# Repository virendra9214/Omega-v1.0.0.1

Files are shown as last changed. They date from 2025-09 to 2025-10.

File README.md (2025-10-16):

Omega – ESP32 STEM Controller Board

Omega is an ESP32-based controller board created by  VIRENDRA SINGH SHEKHAWAT from India to make STEM education, robotics, and IoT more accessible.  
It combines Wi-Fi, BLE, sensor inputs, motor drivers, and easy expansion in one compact design — perfect for classrooms, tinkering labs, hobbyists, and competitions.


  


---

Key Features
- MCU: ESP32-WROOM-32E (Dual-core, Wi-Fi + BLE)
- Programming: Arduino IDE, MicroPython, block-based IDE (PictoBlox-style)
- Motors & Servos:
  - 2× TB6612FNG motor drivers (up to 4 12v motors)
  - 3× Servo headers (5 V PWM)
- Sensors Supported:
  - Ultrasonic, IR, MPU6050 IMU, Color sensor, DHT, analog/digital expansion
- Outputs:
  - WS2812B RGB LED
  - PAM8403 speaker amplifier
- Connectivity:
  - I²C, UART, PWM, ADC, DAC via JST connectors
- Power:
  - Auto USB-C / 12 V barrel jack switching (FDN340P MOSFET)
  - Onboard 5 V & 3.3 V regulation with fuse, diodes, ESD protection

---

 Educational Value
- Free for students, hobbyists, and individual educators.
- Supports hands-on STEM learning: electronics, coding, IoT, robotics
- Beginner-friendly with block-based coding
- Expandable for advanced learners with C++/Python
- Supports Indian education initiatives (NEP 2020, Skill India, Atal Tinkering Labs)

---

Example Projects
- IoT-based smart irrigation system  
- Accident detection and car safety module  
- Line follower / obstacle avoiding robots  
- BLE remote-controlled car  
- Classroom experiments: data logging, servo control, LED patterns  

---

 Repository Contents
- `/Production` → KiCad schematic, PCB, BOM  
- `/firmware` → Arduino / MicroPython example codes  
- `/datasheets` → Datasheets, pin mapping, tutorials  
- `/codes` → Ready-to-run projects for students and testing after production 

---

License
This project is released under the Omega Educational License (OEL-1.0).  
-  Free for education, research, and personal use  
-  Commercial use requires a paid license from the creator  
-  Significant design modifications and redistributions are not allowed  
youtube link:https://www.youtube.com/@LEARN_OMEGA
📩 Contact: virendrasinghshekhawat786@gmail.com for commercial licensing inquiries.







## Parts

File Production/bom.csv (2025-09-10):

Designator | Footprint | Quantity | Value | LCSC Part #
_3, _2, |  | 3
C1, C11, C2, C39, C40, C41, C42, C43, C44, C5 | 0805 | 10 | 100nf
C10, C12 | 0805 | 2 | 10uf
C25, C26 | 0603 | 2 | 10nf
C27 | 0603 | 1 | 2.2nf/16v
C28, C49, C50, C51 | 0603 | 4 | 0.1uf
C29, C30 | CAP_EEETC1V470V | 2 | 47uf/35v
C31, C32 | 0805 | 2 | 100n
C33, C34 | 0805 | 2 | 47uf/25v
C35, C36, C57 | 0805 | 3 | 0.1uf
C37 | 0603 | 1 | 10uf/25v
C38 | 0603 | 1 | 1uf/16V(10%)
C47, C48 | CAP_EEETC1V470V | 2 | 470uf/25V
C52 | 0603 | 1 | 10uF
C53, C54 | 0805 | 2 | 1uf
C55 | 0805 | 1 | 0.47uf
D1 | LED_WS2812B_PLCC4_5.0x5.0mm_P3.2mm | 1 | WS2812B
D3 | D_SMA | 1 | M7
D4 | 0805 | 1 | LED(RED)
D5 | 0805 | 1 | LED
D6 | D_SOD-123 | 1 | 1N5819
D7 | 0805 | 1 | LED (BLUE)
D8 | 0805 | 1 | LED (GREEN)
F1 | FUSER_MF-MSMF110_16-2 | 1 | MF-MSMF110_16-2
J10 | JST_EH_B4B-EH-A_1x04_P2.50mm_Vertical | 1 | ULTRASONIC
J17 | JST_EH_B5B-EH-A_1x05_P2.50mm_Vertical | 1 | POWER
J18 | JST_EH_B3B-EH-A_1x03_P2.50mm_Vertical | 1 | IR1
J20 | BarrelJack_GCT_DCJ200-10-A_Horizontal | 1 | DCJ200-10-A-XX-K_REVA
J21 | JST_EH_B2B-EH-A_1x02_P2.50mm_Vertical | 1 | M1
J22 | JST_EH_B2B-EH-A_1x02_P2.50mm_Vertical | 1 | M2
J23 | JST_EH_B2B-EH-A_1x02_P2.50mm_Vertical | 1 | M3
J25 | JST_EH_B3B-EH-A_1x03_P2.50mm_Vertical | 1 | IR2
J26 | JST_EH_B7B-EH-A_1x07_P2.50mm_Vertical | 1 | Conn_01x07_Socket
J27 | JST_EH_B3B-EH-A_1x03_P2.50mm_Vertical | 1 | S1
J28 | JST_EH_B3B-EH-A_1x03_P2.50mm_Vertical | 1 | S2
J29 | JST_EH_B2B-EH-A_1x02_P2.50mm_Vertical | 1 | Speaker
JUSB1 | USB_C_Receptacle_GCT_USB4105-xx-A_16P_TopMnt_Horizontal | 1 | USB_C_Receptacle_USB2.0
Q1 | SuperSOT-3 | 1 | FDN340P
Q4, Q5 | SOT-23 | 2 | SS8050
R1, R17, R2 | 0805 | 3 | 5.1k
R13 | 0603 | 1 | 1k
R14, R15, R16, R4, R5 | 0603 | 5 | 4.7k
R18, R19 | 0805 | 2 | 10k
R20, R36, R37 | 0805 | 3 | 1k
R21 | 0603 | 1 | 22.1k(1%)
R22 | 0603 | 1 | 47.5k(1%)
R23 | 0603 | 1 | 1k(1%)
R24 | 0603 | 1 | 10k(1%)(NC)
R25, R26, R29, R30 | 0603 | 4 | 0(1%)
R27, R28 | 0603 | 2 | 10k(1%)
R31, R32 | 0603 | 2 | 10k
R35 | 0805 | 1 | 10k(1%)
R9 | 0603 | 1 | 100k
SW1 | SW_SPST_PTS810 | 1 | BOOT
SW2 | SW_SPST_PTS810 | 1 | RESET
U10 | SOT230P700X180-4N | 1 | NCP1117ST50T3G
U11 | MSOP-8_3x3mm_P0.65mm | 1 | LMV358IDGK
U12 | SOT-223-3_TabPin2 | 1 | AMS1117-3.3
U13 | QFN-28-1EP_5x5mm_P0.5mm_EP3.35x3.35mm | 1 | CP2102N-A02-GQFN28
U14, U15 | SSOP-24_5.3x8.2mm_P0.65mm | 2 | TB6612FNG
U16 | SOP-16_3.9x9.9mm_P1.27mm | 1 | PAM8403D
U18 | ESP32-WROOM-32 | 1 | ESP32-WROOM-32
U2 | Diodes_UDFN-10_1.0x2.5mm_P0.5mm | 1 | ESD7104MUTAG
U6 | InvenSense_QFN-24_4x4mm_P0.5mm | 1 | MPU-6050
U8 | TSSOP-20_4.4x6.5mm_P0.65mm | 1 | TXS0108EPW

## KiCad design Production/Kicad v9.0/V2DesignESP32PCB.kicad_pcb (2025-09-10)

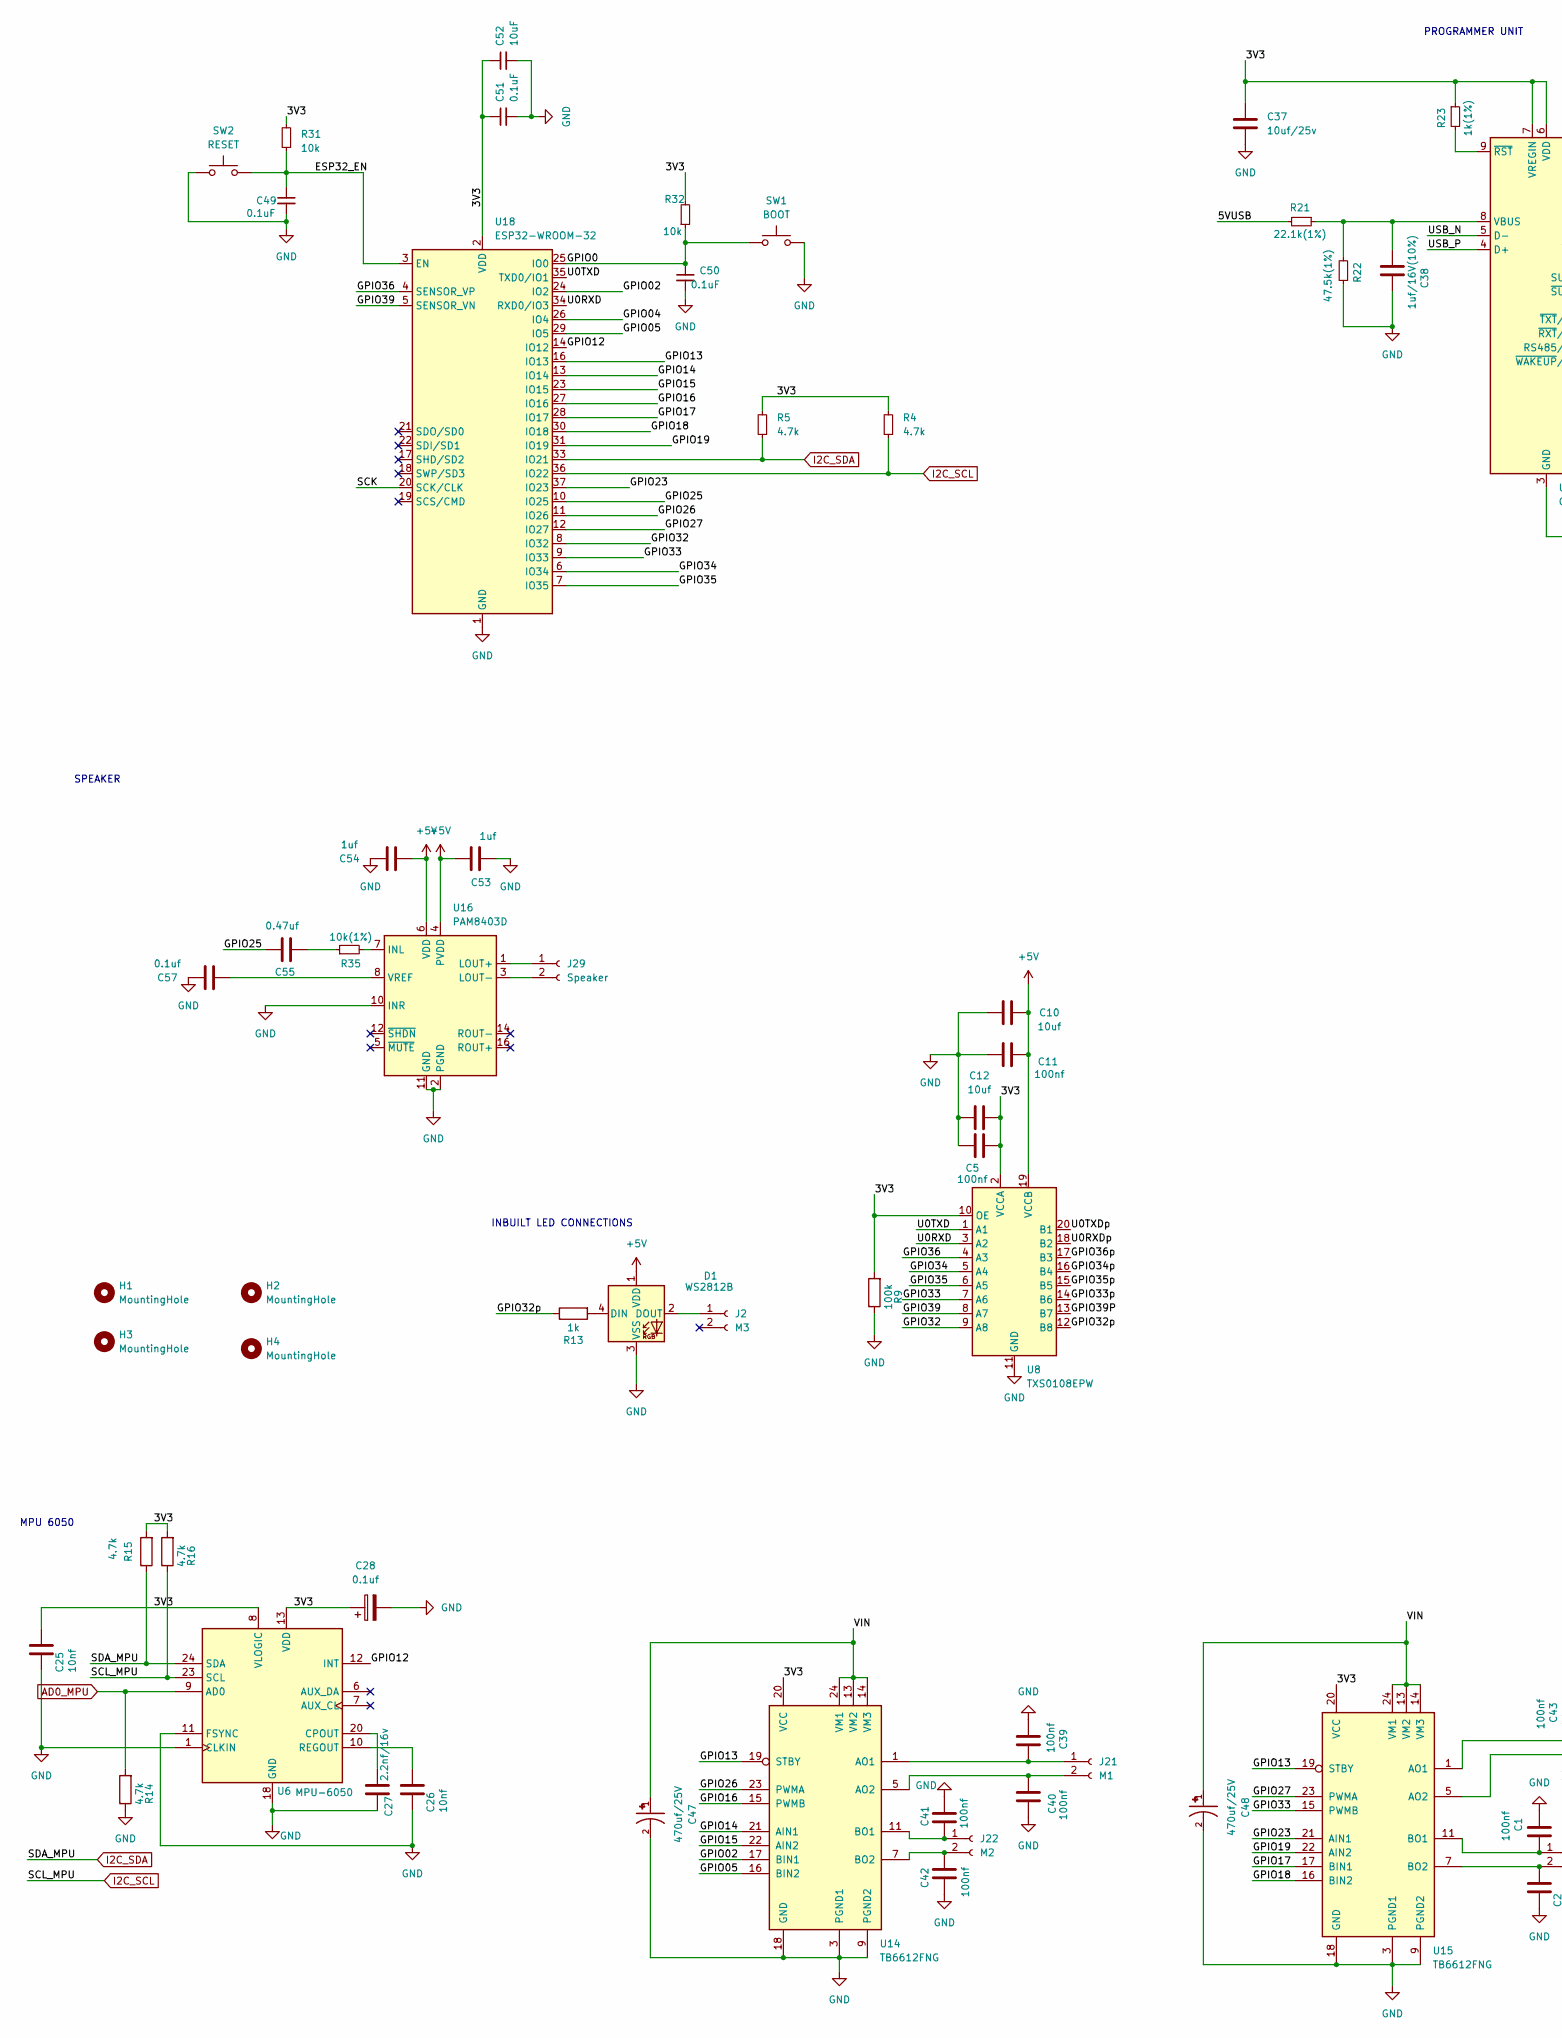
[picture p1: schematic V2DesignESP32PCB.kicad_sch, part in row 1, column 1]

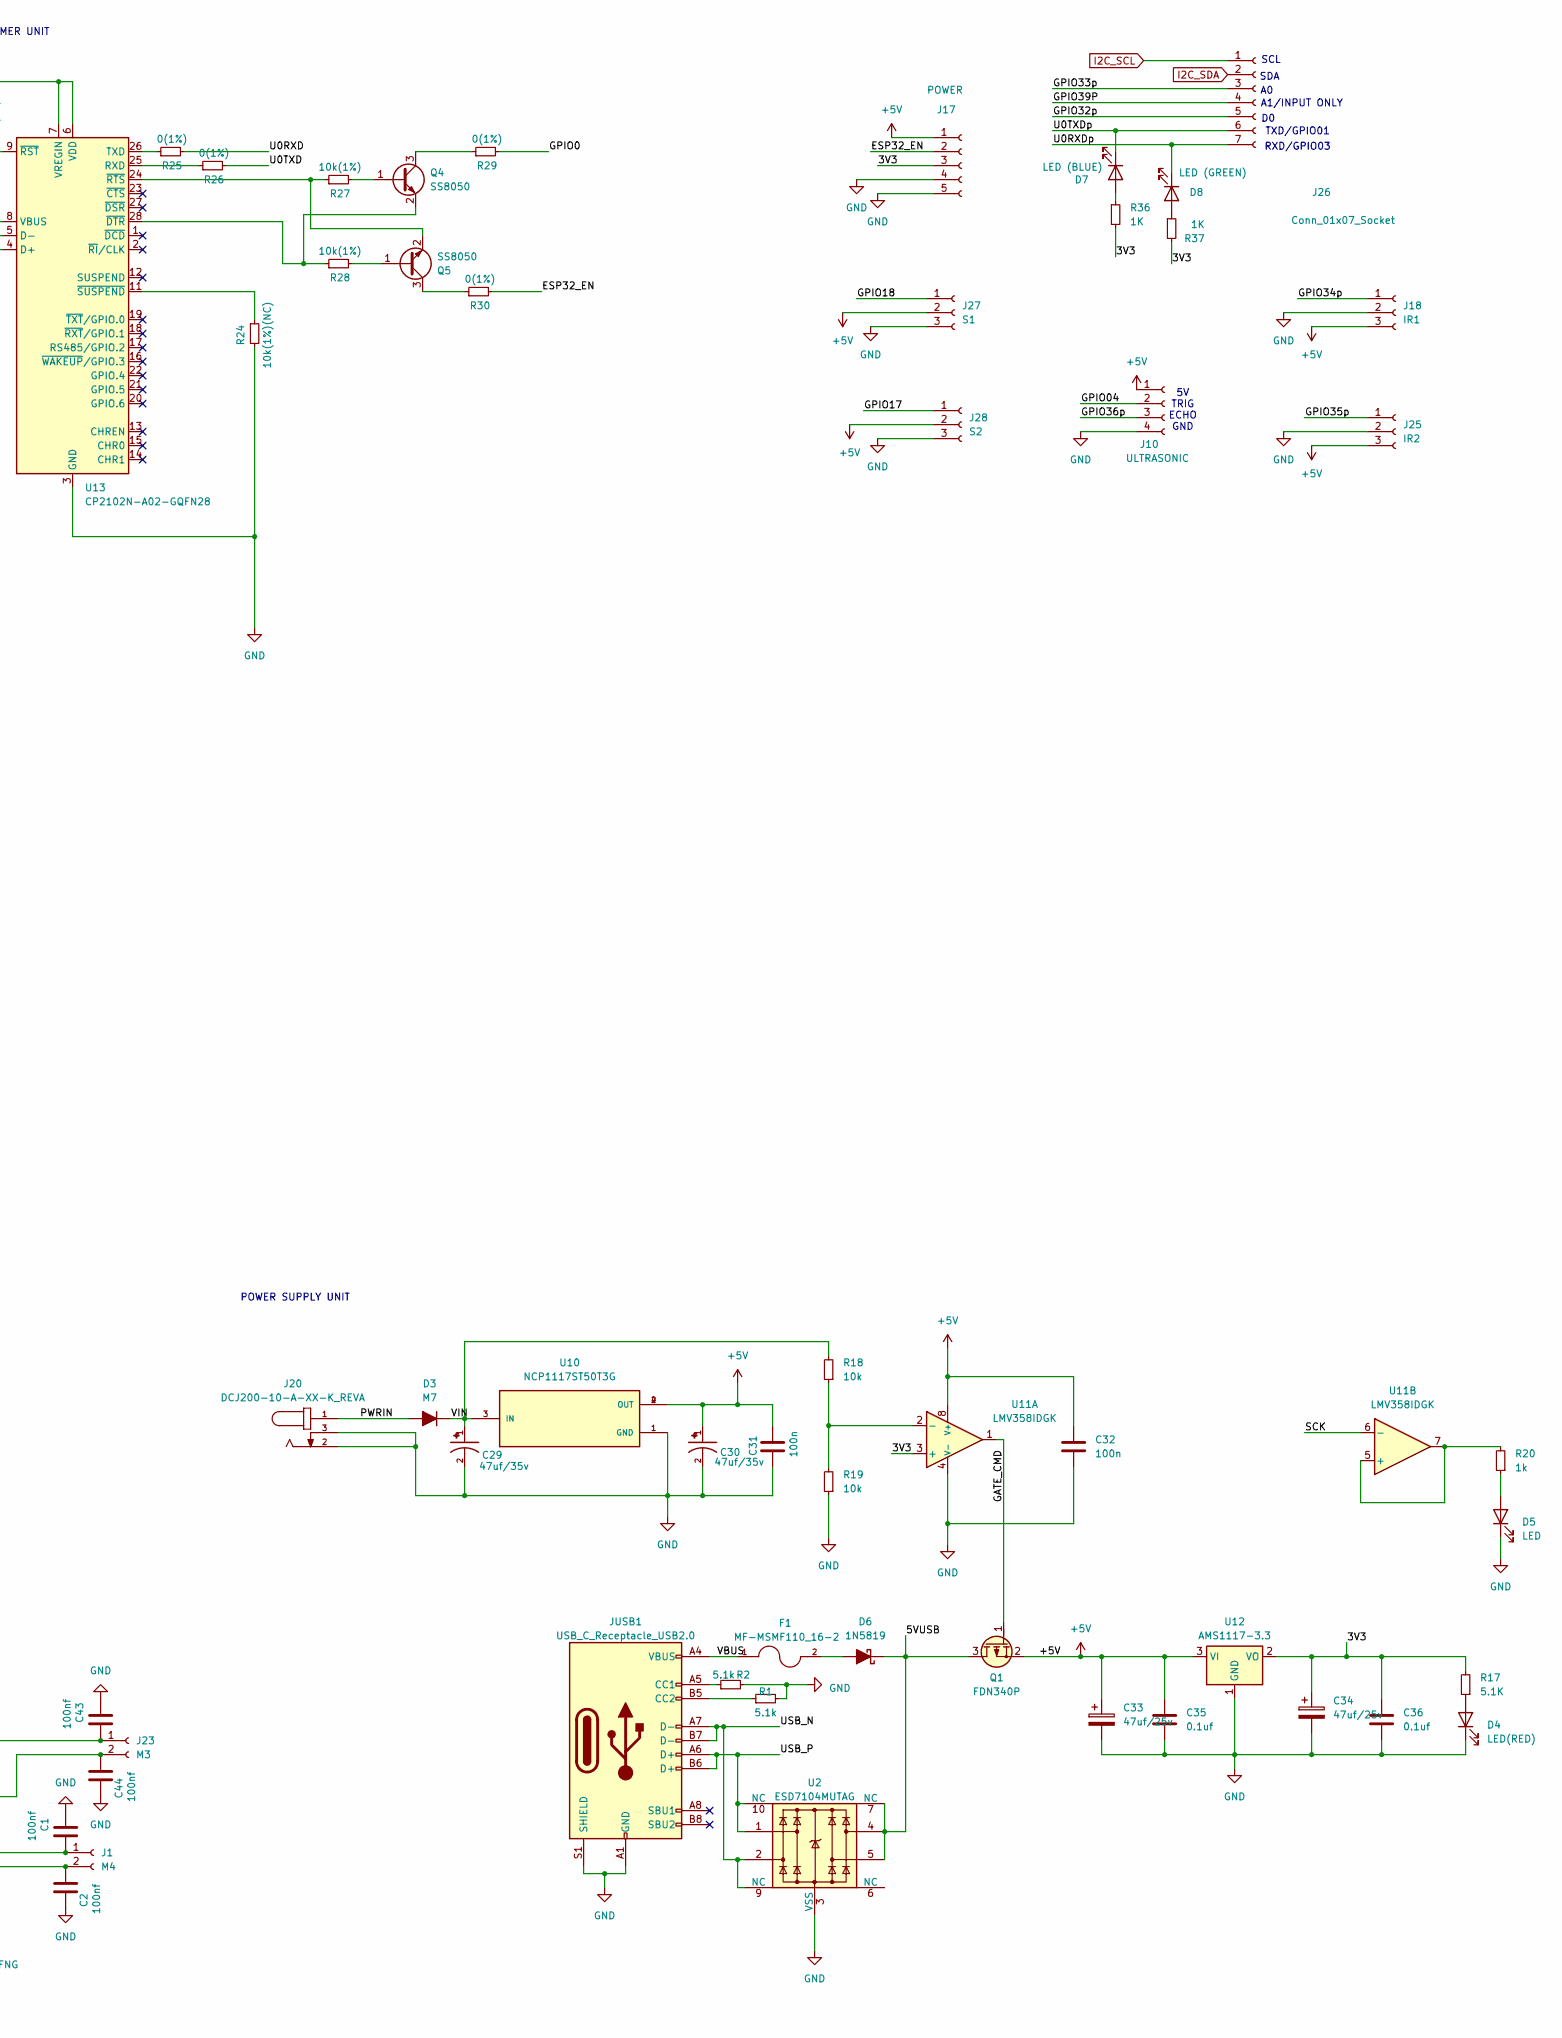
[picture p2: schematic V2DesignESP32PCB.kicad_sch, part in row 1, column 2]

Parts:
C1, C2, C5, C11, C39, C40, C41, C42, C43, C44: 100nf; C_0805_2012Metric
C10, C12: 10uf; C_0805_2012Metric
C25, C26: 10nf; C_0603_1608Metric
C27: 2.2nf/16v; C_0603_1608Metric
C28: 0.1uf; C_0603_1608Metric
C29, C30: 47uf/35v; CAP_EEETC1V470V; PARTREV 10-Oct-19
C31, C32: 100n; C_0805_2012Metric
C33, C34: 47uf/25v; C_0805_2012Metric
C35, C36, C57: 0.1uf; C_0805_2012Metric
C37: 10uf/25v; C_0603_1608Metric
C38: 1uf/16V(10%); C_0603_1608Metric
C47, C48: 470uf/25V; CAP_EEETC1V470V; PARTREV 10-Oct-19
C49, C50, C51: 0.1uF; C_0603_1608Metric; MANUFECTURER PART NUMBER ${ITEM_NUMBER}
C52: 10uF; C_0603_1608Metric; MANUFECTURER PART NUMBER ${ITEM_NUMBER}
C53, C54: 1uf; C_0805_2012Metric
C55: 0.47uf; C_0805_2012Metric
D1: WS2812B; LED_WS2812B_PLCC4_5.0x5.0mm_P3.2mm; MANUFECTURER PART NUMBER ${ITEM_NUMBER}
D3: M7; D_SMA
D4: LED(RED); LED_0805_2012Metric; MANUFECTURER PART NUMBER ${ITEM_NUMBER}
D5: LED; LED_0805_2012Metric; MANUFECTURER PART NUMBER ${ITEM_NUMBER}
D6: 1N5819; D_SOD-123
D7: LED (BLUE); LED_0805_2012Metric; MANUFECTURER PART NUMBER ${ITEM_NUMBER}
D8: LED (GREEN); LED_0805_2012Metric; MANUFECTURER PART NUMBER ${ITEM_NUMBER}
F1: MF-MSMF110_16-2; FUSER_MF-MSMF110_16-2
H1, H2, H3, H4: MountingHole; MountingHole_4mm
J1: M4; MANUFECTURER PART NUMBER ${ITEM_NUMBER}
J2, J23: M3; JST_EH_B2B-EH-A_1x02_P2.50mm_Vertical; MANUFECTURER PART NUMBER ${ITEM_NUMBER}
J10: ULTRASONIC; JST_EH_B4B-EH-A_1x04_P2.50mm_Vertical; MANUFECTURER PART NUMBER ${ITEM_NUMBER}
J17: POWER; JST_EH_B5B-EH-A_1x05_P2.50mm_Vertical
J18: IR1; JST_EH_B3B-EH-A_1x03_P2.50mm_Vertical; MANUFECTURER PART NUMBER ${ITEM_NUMBER}
J20: DCJ200-10-A-XX-K_REVA; BarrelJack_GCT_DCJ200-10-A_Horizontal; PARTREV A
J21: M1; JST_EH_B2B-EH-A_1x02_P2.50mm_Vertical; MANUFECTURER PART NUMBER ${ITEM_NUMBER}
J22: M2; JST_EH_B2B-EH-A_1x02_P2.50mm_Vertical; MANUFECTURER PART NUMBER ${ITEM_NUMBER}
J25: IR2; JST_EH_B3B-EH-A_1x03_P2.50mm_Vertical; MANUFECTURER PART NUMBER ${ITEM_NUMBER}
J26: Conn_01x07_Socket; JST_EH_B7B-EH-A_1x07_P2.50mm_Vertical
J27: S1; JST_EH_B3B-EH-A_1x03_P2.50mm_Vertical; MANUFECTURER PART NUMBER ${ITEM_NUMBER}
J28: S2; JST_EH_B3B-EH-A_1x03_P2.50mm_Vertical; MANUFECTURER PART NUMBER ${ITEM_NUMBER}
J29: Speaker; JST_EH_B2B-EH-A_1x02_P2.50mm_Vertical; MANUFECTURER PART NUMBER ${ITEM_NUMBER}
JUSB1: USB_C_Receptacle_USB2.0; USB_C_Receptacle_GCT_USB4105-xx-A_16P_TopMnt_Horizontal; MANUFECTURER PART NUMBER ${ITEM_NUMBER}
Q1: FDN340P; SuperSOT-3
Q4, Q5: SS8050; SOT-23
R1, R2: 5.1k; R_0805_2012Metric; MANUFECTURER PART NUMBER ${ITEM_NUMBER}
R4, R5: 4.7k; R_0603_1608Metric; MANUFECTURER PART NUMBER ${ITEM_NUMBER}
R9: 100k; R_0603_1608Metric
R13: 1k; R_0603_1608Metric
R14, R15, R16: 4.7k; R_0603_1608Metric
R17: 5.1K; R_0805_2012Metric; MANUFECTURER PART NUMBER ${ITEM_NUMBER}
R18, R19: 10k; R_0805_2012Metric; MANUFECTURER PART NUMBER ${ITEM_NUMBER}
R20: 1k; R_0805_2012Metric; MANUFECTURER PART NUMBER ${ITEM_NUMBER}
R21: 22.1k(1%); R_0603_1608Metric; MANUFECTURER PART NUMBER ${ITEM_NUMBER}
R22: 47.5k(1%); R_0603_1608Metric; MANUFECTURER PART NUMBER ${ITEM_NUMBER}
R23: 1k(1%); R_0603_1608Metric; MANUFECTURER PART NUMBER ${ITEM_NUMBER}
R24: 10k(1%)(NC); R_0603_1608Metric; MANUFECTURER PART NUMBER ${ITEM_NUMBER}
R25, R26, R29, R30: 0(1%); R_0603_1608Metric; MANUFECTURER PART NUMBER ${ITEM_NUMBER}
R27, R28: 10k(1%); R_0603_1608Metric; MANUFECTURER PART NUMBER ${ITEM_NUMBER}
R31, R32: 10k; R_0603_1608Metric; MANUFECTURER PART NUMBER ${ITEM_NUMBER}
R35: 10k(1%); R_0805_2012Metric; MANUFECTURER PART NUMBER ${ITEM_NUMBER}
R36, R37: 1K; R_0805_2012Metric; MANUFECTURER PART NUMBER ${ITEM_NUMBER}
SW1: BOOT; SW_SPST_PTS810
SW2: RESET; SW_SPST_PTS810
U2: ESD7104MUTAG; Diodes_UDFN-10_1.0x2.5mm_P0.5mm; MANUFECTURER PART NUMBER ${ITEM_NUMBER}
U6: MPU-6050; InvenSense_QFN-24_4x4mm_P0.5mm
U8: TXS0108EPW; TSSOP-20_4.4x6.5mm_P0.65mm
U10: NCP1117ST50T3G; SOT230P700X180-4N; DigiKey_Part_Number NCP1117ST50T3GOSTR-ND
U11: LMV358IDGK; MSOP-8_3x3mm_P0.65mm
U12: AMS1117-3.3; SOT-223-3_TabPin2
U13: CP2102N-A02-GQFN28; QFN-28-1EP_5x5mm_P0.5mm_EP3.35x3.35mm
U14, U15: TB6612FNG; SSOP-24_5.3x8.2mm_P0.65mm
U16: PAM8403D; SOP-16_3.9x9.9mm_P1.27mm
U18: ESP32-WROOM-32

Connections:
+5V: C10.2, C11.1, C30.1, C31.1, C32.1, C33.1, C35.1, C53.2, C54.1, D1.1 (VDD), J10.1, J17.1, J18.3, J25.3, J27.2, J28.2, Q1.2 (S), U8.19 (VCCB), U10.2 (OUT), U10.4 (OUT), U11.8 (V+), U12.3 (VI), U16.4 (PVDD), U16.6 (VDD), U16.13 (PVDD)
/3V3: C5.1, C12.2, C25.1, C28.1, C34.1, C36.1, C37.1, C51.1, C52.1, J17.3, R4.2, R5.2, R9.2, R15.2, R16.2, R17.2, R23.1, R31.2, R32.2, R36.2, R37.2, U6.8 (VLOGIC), U6.13 (VDD), U8.2 (VCCA), U8.10 (OE), U11.3 (+), U12.2 (VO), U13.6 (VDD), U13.7 (VREGIN), U14.20 (VCC), U15.20 (VCC), U18.2 (VDD)
/5VUSB: D6.1 (K), Q1.3 (D), R21.2, U2.4, U2.5, U2.7 (NC)
/ESP32_EN: C49.1, J17.2, R30.2, R31.1, SW2.2, U18.3 (EN)
/GATE_CMD: Q1.1 (G), U11.1
/GPIO0: C50.1, R29.2, R32.1, SW1.1, U18.25 (IO0)
/GPIO02: U14.17 (BIN1), U18.24 (IO2)
/GPIO04: J10.2, U18.26 (IO4)
/GPIO05: U14.16 (BIN2), U18.29 (IO5)
/GPIO12: U6.12 (INT), U18.14 (IO12)
/GPIO13: U14.19 (STBY), U15.19 (STBY), U18.16 (IO13)
/GPIO14: U14.21 (AIN1), U18.13 (IO14)
/GPIO15: U14.22 (AIN2), U18.23 (IO15)
/GPIO16: U14.15 (PWMB), U18.27 (IO16)
/GPIO17: J28.1, U15.17 (BIN1), U18.28 (IO17)
/GPIO18: J27.1, U15.16 (BIN2), U18.30 (IO18)
/GPIO19: U15.22 (AIN2), U18.31 (IO19)
/GPIO23: U15.21 (AIN1), U18.37 (IO23)
/GPIO25: C55.2, U18.10 (IO25)
/GPIO26: U14.23 (PWMA), U18.11 (IO26)
/GPIO27: U15.23 (PWMA), U18.12 (IO27)
/GPIO32: U8.9 (A8), U18.8 (IO32)
/GPIO32p: J26.5, R13.1, U8.12 (B8)
/GPIO33: U8.7 (A6), U15.15 (PWMB), U18.9 (IO33)
/GPIO33p: J26.3, U8.14 (B6)
/GPIO34: U8.5 (A4), U18.6 (IO34)
/GPIO34p: J18.1, U8.16 (B4)
/GPIO35: U8.6 (A5), U18.7 (IO35)
/GPIO35p: J25.1, U8.15 (B5)
/GPIO36: U8.4 (A3), U18.4 (SENSOR_VP)
/GPIO36p: J10.3, U8.17 (B3)
/GPIO39: U8.8 (A7), U18.5 (SENSOR_VN)
/GPIO39P: J26.4, U8.13 (B7)
/PWRIN: D3.2 (A), J20.1
/SCK: U11.6 (-), U18.20 (SCK/CLK)
/U0RXD: R25.2, U8.3 (A2), U18.34 (RXD0/IO3)
/U0RXDp: D8.1 (K), J26.7, U8.18 (B2)
/U0TXD: R26.2, U8.1 (A1), U18.35 (TXD0/IO1)
/U0TXDp: D7.1 (K), J26.6, U8.20 (B1)
/USB_N: JUSB1.A7 (D-), JUSB1.B7 (D-), U2.2, U2.9 (NC), U13.5 (D-)
/USB_P: JUSB1.A6 (D+), JUSB1.B6 (D+), U2.1, U2.10 (NC), U13.4 (D+)
/VBUS: F1.1, JUSB1.A4 (VBUS), JUSB1.A9 (VBUS), JUSB1.B4 (VBUS), JUSB1.B9 (VBUS)
/VIN: C29.1, C47.1, C48.1, D3.1 (K), R18.2, U10.3 (IN), U14.13 (VM2), U14.14 (VM3), U14.24 (VM1), U15.13 (VM2), U15.14 (VM3), U15.24 (VM1)
AD0_MPU: R14.2, U6.9 (AD0)
GND: C1.2, C2.2, C5.2, C10.1, C11.2, C12.1, C25.2, C26.2, C27.2, C28.2, C29.2, C30.2, C31.2, C32.2, C33.2, C34.2, C35.2, C36.2, C37.2, C38.2, C39.2, C40.2, C41.2, C42.2, C43.2, C44.2, C47.2, C48.2, C49.2, C50.2, C51.2, C52.2, C53.1, C54.2, C57.2, D1.3 (VSS), D4.1 (K), D5.1 (K), J10.4, J17.4, J17.5, J18.2, J20.2, J20.3, J25.2, J27.3, J28.3, JUSB1.A1 (GND), JUSB1.A12 (GND), JUSB1.B1 (GND), JUSB1.B12 (GND), JUSB1.S1 (SHIELD), R1.2, R2.2, R9.1, R14.1, R19.1, R22.1, R24.2, SW1.2, SW2.1, U2.3 (VSS), U2.8 (VSS), U6.1 (CLKIN), U6.11 (FSYNC), U6.18 (GND), U8.11 (GND), U10.1 (GND), U11.4 (V-), U12.1 (GND), U13.3 (GND), U13.29 (GND), U14.3 (PGND1), U14.4 (PGND1), U14.9 (PGND2), U14.10 (PGND2), U14.18 (GND), U15.3 (PGND1), U15.4 (PGND1), U15.9 (PGND2), U15.10 (PGND2), U15.18 (GND), U16.2 (PGND), U16.10 (INR), U16.11 (GND), U16.15 (PGND), U18.1 (GND), U18.15 (GND), U18.38 (GND), U18.39 (GND)
I2C_SCL: J26.1, R4.1, R16.1, U6.23 (SCL), U18.36 (IO22)
I2C_SDA: J26.2, R5.1, R15.1, U6.24 (SDA), U18.33 (IO21)
unnamed: C55.1, R35.1
unnamed: D1.4 (DIN), R13.2
unnamed: D1.2 (DOUT), J2.1
unnamed: D4.2 (A), R17.1
unnamed: D5.2 (A), R20.1
unnamed: D6.2 (A), F1.2
unnamed: D7.2 (A), R36.1
unnamed: D8.2 (A), R37.1
unnamed: C1.1, J1.1, U15.11 (BO1), U15.12 (BO1)
unnamed: C2.1, J1.2, U15.7 (BO2), U15.8 (BO2)
unnamed: C39.1, J21.1, U14.1 (AO1), U14.2 (AO1)
unnamed: C40.1, J21.2, U14.5 (AO2), U14.6 (AO2)
unnamed: C41.1, J22.1, U14.11 (BO1), U14.12 (BO1)
unnamed: C42.1, J22.2, U14.7 (BO2), U14.8 (BO2)
unnamed: C43.1, J23.1, U15.1 (AO1), U15.2 (AO1)
unnamed: C44.1, J23.2, U15.5 (AO2), U15.6 (AO2)
unnamed: J29.1, U16.1 (LOUT+)
unnamed: J29.2, U16.3 (LOUT-)
unnamed: JUSB1.A5 (CC1), R2.1
unnamed: JUSB1.B5 (CC2), R1.1
unnamed: Q4.1 (B), R27.2
unnamed: Q4.3 (C), R29.1
unnamed: Q4.2 (E), R28.1, U13.28 (~DTR)
unnamed: Q5.1 (B), R28.2
unnamed: Q5.3 (C), R30.1
unnamed: Q5.2 (E), R27.1, U13.24 (~RTS)
unnamed: C27.1, U6.20 (CPOUT)
unnamed: C26.1, U6.10 (REGOUT)
unnamed: R18.1, R19.2, U11.2 (-)
unnamed: R20.2, U11.5 (+), U11.7
unnamed: R26.1, U13.25 (RXD)
unnamed: R25.1, U13.26 (TXD)
unnamed: C38.1, R21.1, R22.2, U13.8 (VBUS)
unnamed: R23.2, U13.9 (~RST)
unnamed: R24.1, U13.11 (~SUSPEND)
unnamed: R35.2, U16.7 (INL)
unnamed: C57.1, U16.8 (VREF)

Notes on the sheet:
PROGRAMMER UNIT
SCL
MPU 6050
INBUILT LED CONNECTIONS
A1/INPUT ONLY
SDA
5V TRIG ECHO GND
POWER SUPPLY UNIT
RXD/GPIO03
SPEAKER
TXD/GPIO01

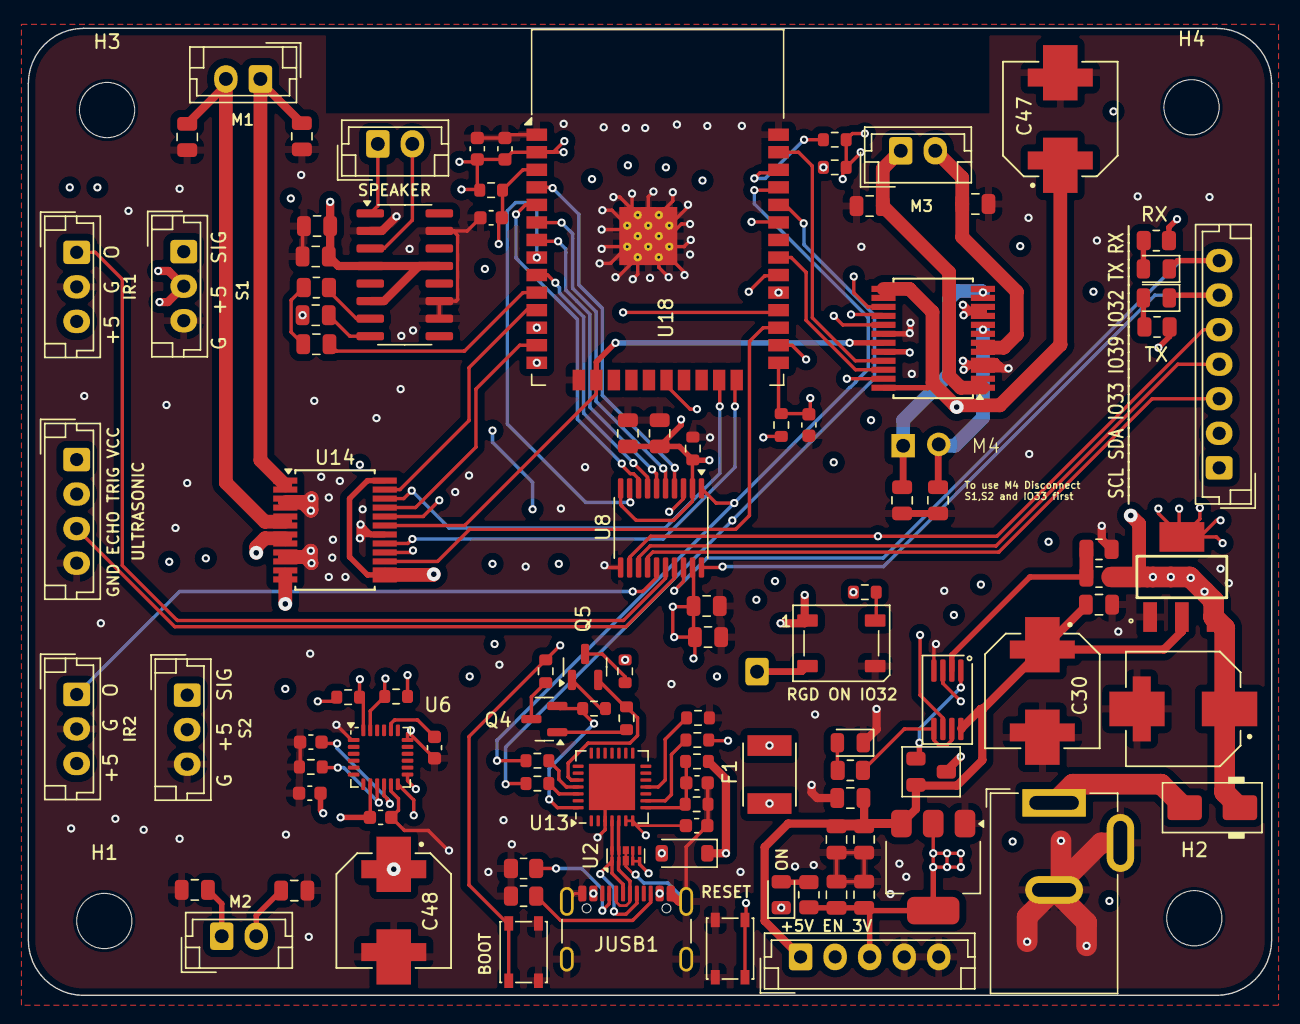
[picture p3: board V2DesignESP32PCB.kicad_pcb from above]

Board: 4 copper layers, 90.0 x 70.0 mm, 105 parts (0 on the bottom side), 83 nets.

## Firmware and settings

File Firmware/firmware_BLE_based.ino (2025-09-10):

/*
  Omega Firmware (BLE Edition)
  Version: 1.0.0.2 (BLE switch-over)
  Date: 23-Aug-2025

  Changes vs SPP version:
  - Replaced BluetoothSerial (Classic SPP) with BLE GATT (Nordic UART-like service)
  - RX characteristic (Write/WriteNR) receives command lines (terminated by '\n')
  - TX characteristic (Notify) sends back responses/prints
  - 'SerialBT' calls replaced by blePrint/blePrintln/bleAvailable via a small queue

  Notes:
  - Works with Web Bluetooth and PictoBlox stage-mode BLE
  - Keep commands exactly as before (e.g., Move_motor_M1_Forward_at_42_%speed_for_2_seconds) 
  - If you send long lines, the BLE MTU splits them; this code reassembles by '\n'
*/

#include <Arduino.h>
#include <BLEDevice.h>
#include <BLEServer.h>
#include <BLEUtils.h>
#include <BLE2902.h>

#include <ESP32Servo.h>
#include <Adafruit_NeoPixel.h>
#include "driver/dac.h"
#include <Wire.h>
#include <LiquidCrystal_I2C.h>
#include "DHT.h"

// ================= BLE (Nordic UART-like) =================
// Service/Characteristic UUIDs (Nordic UART Service pattern)
#define BLE_SERVICE_UUID     "6E400001-B5A3-F393-E0A9-E50E24DCCA9E"
#define BLE_CHAR_RX_UUID     "6E400002-B5A3-F393-E0A9-E50E24DCCA9E" // Write from Central -> ESP32
#define BLE_CHAR_TX_UUID     "6E400003-B5A3-F393-E0A9-E50E24DCCA9E" // Notify from ESP32 -> Central

static BLEServer*        g_server = nullptr;
static BLECharacteristic* g_txChar = nullptr;   // notify out
static BLECharacteristic* g_rxChar = nullptr;   // write in
static bool g_deviceConnected = false;

// Simple command queue built from BLE writes
#include <vector>
static String g_rxLineBuffer;
static std::vector<String> g_cmdQueue; // lines ready to process

// Helper: send text back to central
void bleNotify(const String &s) {
  if (!g_deviceConnected || !g_txChar) return;
  // Chunk notifications to <=180 bytes for safety
  size_t i = 0, n = s.length();
  while (i < n) {
    size_t chunk = min((size_t)180, n - i);
    g_txChar->setValue((uint8_t*)s.c_str() + i, chunk);
    g_txChar->notify();
    i += chunk;
    delay(2);
  }
}
void blePrint(const String& s){ bleNotify(s); }
void blePrintln(const String& s){ bleNotify(s + "\n"); }

class RxCallbacks : public BLECharacteristicCallbacks {
  void onWrite(BLECharacteristic* pChar) override {
    std::string v = pChar->getValue();
    if (v.empty()) return;
    for (char c : v) {
      if (c == '\r') continue;
      if (c == '\n') {
        if (g_rxLineBuffer.length()) {
          g_cmdQueue.push_back(g_rxLineBuffer);
          g_rxLineBuffer = "";
        }
      } else {
        g_rxLineBuffer += c;
        // guard excessively long lines
        if (g_rxLineBuffer.length() > 512) {
          g_rxLineBuffer = "";
          blePrintln("Error: line too long");
        }
      }
    }
  }
};

class ServerCallbacks : public BLEServerCallbacks {
  void onConnect(BLEServer* s) override {
    g_deviceConnected = true;
    blePrintln("BLE connected");
  }
  void onDisconnect(BLEServer* s) override {
    g_deviceConnected = false;
    g_cmdQueue.clear();
    g_rxLineBuffer = "";
    BLEDevice::startAdvertising();
  }
};

// =============== Your original peripherals & pins ===============
// Ultrasonic
#define TRIG_PIN 4
#define ECHO_PIN 36 // input-only

// Servos
#define SERVO1_PIN 18
#define SERVO2_PIN 17
Servo myServo1, myServo2;

// WS2812B
#define LED_PIN 32
#define NUM_LEDS 1
Adafruit_NeoPixel strip(NUM_LEDS, LED_PIN, NEO_GRB + NEO_KHZ800);

// Color sensor (TCS3200/TCS230) — WARNING: S1 on TX0 and S2 on RX0 will block flashing if connected.
#define S0  33
#define S1  1   // TX0 (disconnect during upload)
#define S2  3   // RX0 (disconnect during upload)
#define S3  32
#define OUT 39  // input-only
unsigned long redPW, greenPW, bluePW; int red, green, blue;

// DHT11
#define DHTPIN 33
#define DHTTYPE DHT11

// Ext pins
#define IO33 33
#define IO32 32
#define IO39 39
#define RXPIN 3
#define TXPIN 1

// LCD I2C
LiquidCrystal_I2C lcd(0x27,16,2);

// Audio placeholders (no data provided in original code)
// const uint8_t forwardAudio[] PROGMEM = { };
// ... etc
const int forwardLength = 0, backwardLength = 0, leftLength = 0, rightLength = 0, okayLength = 0, hornLength = 0, sosLength = 0;
const int sampleRate = 28000;

// TB6612FNG pins (NOTE: Original code duplicates M1/M3 pins — verify PCB)
const int STBY = 13;
const int PWMB = 16; const int BIN1 = 2;  const int BIN2 = 5;   // M2
const int PWMA = 26; const int AIN1 = 14; const int AIN2 = 15;  // M1
const int PWMC = 26; const int CIN1 = 14; const int CIN2 = 15;  // M3 (shares M1 pins in original)

// Flags & globals (kept from original)
int angle_Servo1=0, angle_Servo2=0;
int speedm1=0,durationm1=0,speedm2=0,durationm2=0,speedm3=0,durationm3=0;
int speedf1=0,durationf1=0,speedb1=0,durationb1=0,speedr1=0,durationr1=0,speedl1=0,durationl1=0;

bool Get_value_ir1_digital=false, Get_value_ir1_analog=false, Get_value_ir2_digital=false, Get_value_ir2_analog=false;
bool Get_Ultrasonic_distance_cm=false, Get_Ultrasonic_distance_inches=false;
bool Rotate_Servo1_to=false, Rotate_Servo2_to=false;
bool Move_motor_M1_Forward_at_=false, Move_motor_M1_Backward_at_=false;
bool Move_motor_M2_Forward_at_=false, Move_motor_M2_Backward_at_=false;
bool Move_motor_M3_Forward_at_=false, Move_motor_M3_Backward_at_=false;
bool Start_Motor_function=false; bool wasConnected=false;
bool Move_Omega_Forward_at_=false, Move_Omega_Backward_at_=false, Move_Omega_Left_at_=false, Move_Omega_Right_at_=false;
bool Stop_M1=true, Stop_M2=true, Stop_M3=true;

bool Get_value_IO39_digital=false, Get_value_IO39_analog=false, Get_value_IO33_digital=false, Get_value_IO33_analog=false;
bool Get_value_IO32_digital=false, Get_value_IO32_analog=false;
bool Write_value_IO33_digital_HIGH=false, Write_value_IO33_digital_LOW=false;
bool Write_value_IO32_digital_HIGH=false, Write_value_IO32_digital_LOW=false;

// ====== helpers ======
long getUltrasonicDistanceCM();
long getUltrasonicDistanceINCHES();
int extractSpeed(String command);
int extractDuration(String command);
void rotateM1Forward(int speedPercent, int seconds);
void rotateM1Backward(int speedPercent, int seconds);
void rotateM2Forward(int speedPercent, int seconds);
void rotateM2Backward(int speedPercent, int seconds);
void rotateM3Forward(int speedPercent, int seconds);
void rotateM3Backward(int speedPercent, int seconds);
void MoveOmegaForward(int speedPercent, int seconds);
void MoveOmegaBackward(int speedPercent, int seconds);
void MoveOmegaLeft(int speedPercent, int seconds);
void MoveOmegaRight(int speedPercent, int seconds);
void setColor(uint8_t r,uint8_t g,uint8_t b);
void turnOffLED();

// Color sensor helpers
void setupColorSensorPins();
void releaseColorSensorPins();
void readColorSensor();

// ===== Command handling via BLE =====
void handleCommand(const String& cmd) {
  String c = cmd; c.trim();
  if (!c.length()) return;

  // Mirrors your original "if (SerialBT.available()) {...}" parser
  if (c.startsWith("Get_value_IR1_digital")) { Get_value_ir1_digital = true; blePrintln("IR1 digital queued"); }
  else if (c.startsWith("Get_value_IR1_analog")) { Get_value_ir1_analog = true; blePrintln("IR1 analog queued"); }
  else if (c.startsWith("Get_value_IR2_digital")) { Get_value_ir2_digital = true; blePrintln("IR2 digital queued"); }
  else if (c.startsWith("Get_value_IR2_analog")) { Get_value_ir2_analog = true; blePrintln("IR2 analog queued"); }

  else if (c.startsWith("Get_Ultrasonic_distance_cm")) { Get_Ultrasonic_distance_cm = true; blePrintln("Ultrasonic cm queued"); }
  else if (c.startsWith("Get_Ultrasonic_distance_inches")) { Get_Ultrasonic_distance_inches = true; blePrintln("Ultrasonic inches queued"); }

  else if (c.startsWith("Rotate_Servo1_to_")) { angle_Servo1 = c.substring(18).toInt(); Rotate_Servo1_to = true; blePrintln("Servo1 rotate queued"); }
  else if (c.startsWith("Rotate_Servo2_to_")) { angle_Servo2 = c.substring(18).toInt(); Rotate_Servo2_to = true; blePrintln("Servo2 rotate queued"); }

  else if (c.startsWith("Move_Omega_Forward_at_"))  { speedf1 = extractSpeed(c); durationf1 = extractDuration(c); Move_Omega_Forward_at_ = true; blePrintln("Omega forward queued"); }
  else if (c.startsWith("Move_Omega_Backward_at_")) { speedb1 = extractSpeed(c); durationb1 = extractDuration(c); Move_Omega_Backward_at_ = true; blePrintln("Omega backward queued"); }
  else if (c.startsWith("Move_Omega_Left_at_"))     { speedl1 = extractSpeed(c); durationl1 = extractDuration(c); Move_Omega_Left_at_ = true; blePrintln("Omega left queued"); }
  else if (c.startsWith("Move_Omega_Right_at_"))    { speedr1 = extractSpeed(c); durationr1 = extractDuration(c); Move_Omega_Right_at_ = true; blePrintln("Omega right queued"); }

  else if (c.startsWith("Stop_M1")) { Stop_M1 = true; blePrintln("Stop M1"); }
  else if (c.startsWith("Stop_M2")) { Stop_M2 = true; blePrintln("Stop M2"); }
  else if (c.startsWith("Stop_M3")) { Stop_M3 = true; blePrintln("Stop M3"); }

  else if (c.startsWith("Move_motor_M1_Forward_at_"))  { speedm1=extractSpeed(c); durationm1=extractDuration(c); Move_motor_M1_Forward_at_=true; blePrintln("M1 FWD queued"); }
  else if (c.startsWith("Move_motor_M1_Backward_at_")) { speedm1=extractSpeed(c); durationm1=extractDuration(c); Move_motor_M1_Backward_at_=true; blePrintln("M1 BWD queued"); }
  else if (c.startsWith("Move_motor_M2_Forward_at_"))  { speedm2=extractSpeed(c); durationm2=extractDuration(c); Move_motor_M2_Forward_at_=true; blePrintln("M2 FWD queued"); }
  else if (c.startsWith("Move_motor_M2_Backward_at_")) { speedm2=extractSpeed(c); durationm2=extractDuration(c); Move_motor_M2_Backward_at_=true; blePrintln("M2 BWD queued"); }
  else if (c.startsWith("Move_motor_M3_Forward_at_"))  { speedm3=extractSpeed(c); durationm3=extractDuration(c); Move_motor_M3_Forward_at_=true; blePrintln("M3 FWD queued"); }
  else if (c.startsWith("Move_motor_M3_Backward_at_")) { speedm3=extractSpeed(c); durationm3=extractDuration(c); Move_motor_M3_Backward_at_=true; blePrintln("M3 BWD queued"); }

  else if (c.startsWith("Start_Motor_function")) { Start_Motor_function = true; digitalWrite(STBY, HIGH); blePrintln("Motors ON"); }
  else if (c.startsWith("Turn_off_Motor_function")) { Start_Motor_function = false; digitalWrite(STBY, LOW); blePrintln("Motors OFF"); }

  else if (c.startsWith("Glow_RGB_With_R")) {
    int rIndex = c.indexOf('R') + 1;
    int gIndex = c.indexOf("_G") + 2;
    int bIndex = c.indexOf("_B") + 2;
    if (rIndex>0 && gIndex>0 && bIndex>0) {
      int rValue = c.substring(rIndex, c.indexOf("_G")).toInt();
      int gValue = c.substring(gIndex, c.indexOf("_B")).toInt();
      int bValue = c.substring(bIndex).toInt();
      setColor(rValue,gValue,bValue);
      blePrintln("LED set");
    }
  }
  else if (c.equalsIgnoreCase("Turn_Off_LED")) { turnOffLED(); blePrintln("LED off"); }

  else if (c.startsWith("Display_Text_")) {
    // Parse like original
    int startQuote = c.indexOf('\'');
    int endQuote = c.lastIndexOf('\'');
    if (startQuote!=-1 && endQuote!=-1 && startQuote!=endQuote) {
      String text = c.substring(startQuote+1, endQuote);
      int col=0,row=0;
      int colIndex=c.indexOf("coulmn_"); if(colIndex!=-1){ int colEnd=c.indexOf('_', colIndex+7); col = c.substring(colIndex+7, colEnd).toInt()-1; }
      int rowIndex=c.indexOf("raw_");    if(rowIndex!=-1){ row = c.substring(rowIndex+4).toInt()-1; }
      lcd.setCursor(col,row); lcd.print(text);
      blePrintln("LCD updated");
    }
  }

  else if (c.equalsIgnoreCase("Clear_16x2_LCD_Display")) { lcd.clear(); blePrintln("LCD cleared"); }

  else if (c.equalsIgnoreCase("Get_value_color_sensor")) {
    setupColorSensorPins(); readColorSensor(); releaseColorSensorPins();
    String out = String("R:")+red+"  G:"+green+"  B:"+blue; blePrintln(out);
  }

  else if (c.equalsIgnoreCase("Get_value_dht11")) {
    pinMode(DHTPIN, INPUT_PULLUP); delay(50);
    DHT dht(DHTPIN, DHTTYPE); dht.begin(); delay(100);
    float h=dht.readHumidity(), t=dht.readTemperature();
    if (isnan(h)||isnan(t)) blePrintln("Error: DHT11");
    else blePrintln(String("Temperature: ")+t+" *C, Humidity: "+h+" %");
    pinMode(DHTPIN, INPUT);
  }

  else if (c.startsWith("Get_value_IO39_digital")) { Get_value_IO39_digital=true; }
  else if (c.startsWith("Get_value_IO39_analog"))  { Get_value_IO39_analog=true; }
  else if (c.startsWith("Get_value_IO33_digital")) { Get_value_IO33_digital=true; }
  else if (c.startsWith("Get_value_IO33_analog"))  { Get_value_IO33_analog=true; }
  else if (c.startsWith("Get_value_IO32_digital")) { Get_value_IO32_digital=true; }
  else if (c.startsWith("Get_value_IO32_analog"))  { Get_value_IO32_analog=true; }
  else if (c.startsWith("Write_value_IO33_digital_HIGH")) { Write_value_IO33_digital_HIGH=true; }
  else if (c.startsWith("Write_value_IO33_digital_LOW"))  { Write_value_IO33_digital_LOW=true; }
  else if (c.startsWith("Write_value_IO32_digital_HIGH")) { Write_value_IO32_digital_HIGH=true; }
  else if (c.startsWith("Write_value_IO32_digital_LOW"))  { Write_value_IO32_digital_LOW=true; }
  else {
    blePrintln("Unknown cmd");
  }
}

// ===================== setup / loop =====================
void setup(){
  Serial.begin(115200);

  // I2C + LCD
  Wire.begin(21,22);
  lcd.init(); lcd.backlight();

  // Ultrasonic pins
  pinMode(TRIG_PIN, OUTPUT);
  pinMode(ECHO_PIN, INPUT);

  // Servos
  myServo1.attach(SERVO1_PIN, 500, 2000);
  myServo1.write(0);
  myServo2.attach(SERVO2_PIN, 500, 2000); // fixed: use SERVO2_PIN
  myServo2.write(0);

  // Motors
  pinMode(STBY, OUTPUT);
  pinMode(PWMB, OUTPUT); pinMode(BIN1, OUTPUT); pinMode(BIN2, OUTPUT);
  pinMode(PWMA, OUTPUT); pinMode(AIN1, OUTPUT); pinMode(AIN2, OUTPUT);
  pinMode(PWMC, OUTPUT); pinMode(CIN1, OUTPUT); pinMode(CIN2, OUTPUT);

  // LED
  strip.begin(); strip.show();

  // Speaker DAC
  dac_output_enable(DAC_CHANNEL_1); // GPIO25

  // ===== BLE bring-up =====
  BLEDevice::init("OMEGA-001");
  g_server = BLEDevice::createServer();
  g_server->setCallbacks(new ServerCallbacks());

  BLEService* service = g_server->createService(BLE_SERVICE_UUID);
  g_txChar = service->createCharacteristic(BLE_CHAR_TX_UUID, BLECharacteristic::PROPERTY_NOTIFY);
  g_txChar->addDescriptor(new BLE2902());

  g_rxChar = service->createCharacteristic(BLE_CHAR_RX_UUID, BLECharacteristic::PROPERTY_WRITE | BLECharacteristic::PROPERTY_WRITE_NR);
  g_rxChar->setCallbacks(new RxCallbacks());

  service->start();
  BLEAdvertising* adv = BLEDevice::getAdvertising();
  adv->addServiceUUID(BLE_SERVICE_UUID);
  adv->setScanResponse(true);
  adv->setMinPreferred(0x06); // helps iOS
  adv->setMinPreferred(0x12);
  BLEDevice::startAdvertising();

  blePrintln("Waiting for BLE commands...");
}

void loop(){
  // Process incoming command queue built by onWrite
  if (!g_cmdQueue.empty()) {
    String cmd = g_cmdQueue.front();
    g_cmdQueue.erase(g_cmdQueue.begin());
    handleCommand(cmd);
  }

  // === Execute flagged actions (mirrors original) ===
  if (Get_value_ir1_digital){ int v=digitalRead(34); blePrintln(String(v)); Get_value_ir1_digital=false; }
  if (Get_value_ir1_analog){ int v=analogRead(34);  blePrintln(String(v)); Get_value_ir1_analog=false; }
  if (Get_value_ir2_digital){ int v=digitalRead(35); blePrintln(String(v)); Get_value_ir2_digital=false; }
  if (Get_value_ir2_analog){ int v=analogRead(35);  blePrintln(String(v)); Get_value_ir2_analog=false; }

  if (Get_Ultrasonic_distance_cm){ long d=getUltrasonicDistanceCM(); if(d==-1) blePrintln("Error! Check Connections"); else blePrintln(String("Distance: ")+d+" cm"); Get_Ultrasonic_distance_cm=false; }
  if (Get_Ultrasonic_distance_inches){ long d=getUltrasonicDistanceINCHES(); if(d==-1) blePrintln("Error! Check Connections"); else blePrintln(String("Distance: ")+d+" inches"); Get_Ultrasonic_distance_inches=false; }

  if (Rotate_Servo1_to){ if(angle_Servo1>=0 && angle_Servo1<=180){ for(int a=0;a<=angle_Servo1;a++){ myServo1.write(a); delay(20);} blePrintln("Servo1 done"); } else blePrintln("Invalid Servo1 angle"); Rotate_Servo1_to=false; }
  if (Rotate_Servo2_to){ if(angle_Servo2>=0 && angle_Servo2<=180){ for(int a=0;a<=angle_Servo2;a++){ myServo2.write(a); delay(20);} blePrintln("Servo2 done"); } else blePrintln("Invalid Servo2 angle"); Rotate_Servo2_to=false; }

  if (Move_Omega_Forward_at_){ if(speedf1>=0 && speedf1<=100 && durationf1>0) MoveOmegaForward(speedf1,durationf1); Move_Omega_Forward_at_=false; }
  if (Move_Omega_Backward_at_){ if(speedb1>=0 && speedb1<=100 && durationb1>0) MoveOmegaBackward(speedb1,durationb1); Move_Omega_Backward_at_=false; }
  if (Move_Omega_Left_at_){ if(speedl1>=0 && speedl1<=100 && durationl1>0) MoveOmegaLeft(speedl1,durationl1); Move_Omega_Left_at_=false; }
  if (Move_Omega_Right_at_){ if(speedr1>=0 && speedr1<=100 && durationr1>0) MoveOmegaRight(speedr1,durationr1); Move_Omega_Right_at_=false; }

  if (Move_motor_M1_Forward_at_){ if(speedm1>=0 && speedm1<=100 && durationm1>0) rotateM1Forward(speedm1,durationm1); Move_motor_M1_Forward_at_=false; }
  if (Move_motor_M1_Backward_at_){ if(speedm1>=0 && speedm1<=100 && durationm1>0) rotateM1Backward(speedm1,durationm1); Move_motor_M1_Backward_at_=false; }
  if (Move_motor_M2_Forward_at_){ if(speedm2>=0 && speedm2<=100 && durationm2>0) rotateM2Forward(speedm2,durationm2); Move_motor_M2_Forward_at_=false; }
  if (Move_motor_M2_Backward_at_){ if(speedm2>=0 && speedm2<=100 && durationm2>0) rotateM2Backward(speedm2,durationm2); Move_motor_M2_Backward_at_=false; }
  if (Move_motor_M3_Forward_at_){ if(speedm3>=0 && speedm3<=100 && durationm3>0) rotateM3Forward(speedm3,durationm3); Move_motor_M3_Forward_at_=false; }
  if (Move_motor_M3_Backward_at_){ if(speedm3>=0 && speedm3<=100 && durationm3>0) rotateM3Backward(speedm3,durationm3); Move_motor_M3_Backward_at_=false; }

  if (Get_value_IO39_digital){ blePrintln(String(digitalRead(39))); Get_value_IO39_digital=false; }
  if (Get_value_IO39_analog){  blePrintln(String(analogRead(39)));  Get_value_IO39_analog=false; }
  if (Get_value_IO33_digital){ blePrintln(String(digitalRead(33))); Get_value_IO33_digital=false; }
  if (Get_value_IO33_analog){  blePrintln(String(analogRead(33)));  Get_value_IO33_analog=false; }
  if (Get_value_IO32_digital){ blePrintln(String(digitalRead(32))); Get_value_IO32_digital=false; }
  if (Get_value_IO32_analog){  blePrintln(String(analogRead(32)));  Get_value_IO32_analog=false; }

  if (Write_value_IO33_digital_HIGH){ pinMode(IO33,OUTPUT); digitalWrite(IO33,HIGH); delay(100); pinMode(IO33,INPUT_PULLUP); Write_value_IO33_digital_HIGH=false; }
  if (Write_value_IO33_digital_LOW){  pinMode(IO33,OUTPUT); digitalWrite(IO33,LOW);  delay(100); pinMode(IO33,INPUT_PULLDOWN); Write_value_IO33_digital_LOW=false; }
  if (Write_value_IO32_digital_HIGH){ pinMode(IO32,OUTPUT); digitalWrite(IO32,HIGH); delay(100); pinMode(IO32,INPUT_PULLUP); Write_value_IO32_digital_HIGH=false; }
  if (Write_value_IO32_digital_LOW){  pinMode(IO32,OUTPUT); digitalWrite(IO32,LOW);  delay(100); pinMode(IO32,INPUT_PULLDOWN); Write_value_IO32_digital_LOW=false; }
}

// =================== Implementations ===================

// Ultrasonic
long getUltrasonicDistanceCM(){
  digitalWrite(TRIG_PIN, LOW); delayMicroseconds(2);
  digitalWrite(TRIG_PIN, HIGH); delayMicroseconds(10);
  digitalWrite(TRIG_PIN, LOW);
  long duration = pulseIn(ECHO_PIN, HIGH, 30000);
  if (duration==0) return -1;
  return (long)(duration*0.0343/2.0);
}
long getUltrasonicDistanceINCHES(){
  digitalWrite(TRIG_PIN, LOW); delayMicroseconds(2);
  digitalWrite(TRIG_PIN, HIGH); delayMicroseconds(10);
  digitalWrite(TRIG_PIN, LOW);
  long duration = pulseIn(ECHO_PIN, HIGH, 30000);
  if (duration==0) return -1;
  return (long)(duration*0.0135039/2.0);
}

// Extractors
int extractSpeed(String command){ int s=command.indexOf("_at_"); int e=command.indexOf("_%speed"); if(s!=-1 && e!=-1 && e>s){ return command.substring(s+4,e).toInt(); } return -1; }
int extractDuration(String command){ int i=command.lastIndexOf("_for_"); if(i!=-1){ String d=command.substring(i+5); d.replace("_seconds","" ); return d.toInt(); } return 0; }

// Motions
void MoveOmegaForward(int p, int sec){ int pwm = map(p,0,100,0,255); blePrintln(String("Moving Forward ")+p+"% for "+sec+"s");
  digitalWrite(STBY,HIGH); digitalWrite(AIN1,HIGH); digitalWrite(AIN2,LOW); analogWrite(PWMA,pwm);
  digitalWrite(STBY,HIGH); digitalWrite(BIN1,HIGH); digitalWrite(BIN2,LOW); analogWrite(PWMB,pwm);
  delay(sec*1000);
  analogWrite(PWMA,0); digitalWrite(AIN1,LOW); digitalWrite(AIN2,LOW);
  analogWrite(PWMB,0); digitalWrite(BIN1,LOW); digitalWrite(BIN2,LOW);
}
void MoveOmegaBackward(int p, int sec){ int pwm = map(p,0,100,0,255); blePrintln(String("Moving Backward ")+p+"% for "+sec+"s");
  digitalWrite(STBY,HIGH); digitalWrite(AIN1,LOW); digitalWrite(AIN2,HIGH); analogWrite(PWMA,pwm);
  digitalWrite(STBY,HIGH); digitalWrite(BIN1,LOW); digitalWrite(BIN2,HIGH); analogWrite(PWMB,pwm);
  delay(sec*1000);
  analogWrite(PWMA,0); digitalWrite(AIN1,LOW); digitalWrite(AIN2,LOW);
  analogWrite(PWMB,0); digitalWrite(BIN1,LOW); digitalWrite(BIN2,LOW);
}
void MoveOmegaRight(int p, int sec){ int pwm = map(p,0,100,0,255); blePrintln(String("Moving Right ")+p+"% for "+sec+"s");
  digitalWrite(STBY,HIGH); digitalWrite(AIN1,HIGH); digitalWrite(AIN2,LOW); analogWrite(PWMA,pwm);
  digitalWrite(STBY,HIGH); digitalWrite(BIN1,LOW);  digitalWrite(BIN2,HIGH); analogWrite(PWMB,pwm);
  delay(sec*1000);
  analogWrite(PWMA,0); digitalWrite(AIN1,LOW); digitalWrite(AIN2,LOW);
  analogWrite(PWMB,0); digitalWrite(BIN1,LOW); digitalWrite(BIN2,LOW);
}
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

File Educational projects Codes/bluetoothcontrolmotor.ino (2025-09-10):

#include <BluetoothSerial.h>

BluetoothSerial SerialBT;

// Motor driver pin connections
#define STBY 13
#define PWMA 26
#define PWMB 16
#define AIN1 14
#define AIN2 15
#define BIN1 2
#define BIN2 5

// Motor speed (0–255)
int motorSpeed = 255;

void setup() {
  Serial.begin(115200);
  SerialBT.begin("ESP32_Car"); // Bluetooth name
  Serial.println("Bluetooth Car Ready. Connect to 'ESP32_Car'");

  // Set motor pins as outputs
  pinMode(STBY, OUTPUT);
  pinMode(PWMA, OUTPUT);
  pinMode(AIN1, OUTPUT);
  pinMode(AIN2, OUTPUT);
  pinMode(PWMB, OUTPUT);
  pinMode(BIN1, OUTPUT);
  pinMode(BIN2, OUTPUT);

  digitalWrite(STBY, HIGH); // Enable standby
}

void loop() {
  if (SerialBT.available()) {
    String command = SerialBT.readStringUntil('\n');
    command.trim();  // remove extra spaces or \r

    if (command.equalsIgnoreCase("forward")) {
      moveForward();
    } 
    else if (command.equalsIgnoreCase("backward")) {
      moveBackward();
    } 
    else if (command.equalsIgnoreCase("left")) {
      turnLeft();
    } 
    else if (command.equalsIgnoreCase("right")) {
      turnRight();
    } 
    else if (command.equalsIgnoreCase("stop")) {
      stopMotors();
    }
  }
}

// ---------------- Motor Functions ----------------
void moveForward() {
  digitalWrite(AIN1, HIGH);
  digitalWrite(AIN2, LOW);
  digitalWrite(BIN1, HIGH);
  digitalWrite(BIN2, LOW);
  analogWrite(PWMA, motorSpeed);
  analogWrite(PWMB, motorSpeed);
  Serial.println("Forward");
}

void moveBackward() {
  digitalWrite(AIN1, LOW);
  digitalWrite(AIN2, HIGH);
  digitalWrite(BIN1, LOW);
  digitalWrite(BIN2, HIGH);
  analogWrite(PWMA, motorSpeed);
  analogWrite(PWMB, motorSpeed);
  Serial.println("Backward");
}

void turnLeft() {
  digitalWrite(AIN1, LOW);
  digitalWrite(AIN2, HIGH);
  digitalWrite(BIN1, HIGH);
  digitalWrite(BIN2, LOW);
  analogWrite(PWMA, motorSpeed);
  analogWrite(PWMB, motorSpeed);
  Serial.println("Left");
}

void turnRight() {
  digitalWrite(AIN1, HIGH);
  digitalWrite(AIN2, LOW);
  digitalWrite(BIN1, LOW);
  digitalWrite(BIN2, HIGH);
  analogWrite(PWMA, motorSpeed);
  analogWrite(PWMB, motorSpeed);
  Serial.println("Right");
}

void stopMotors() {
  analogWrite(PWMA, 0);
  analogWrite(PWMB, 0);
  Serial.println("Stop");
}

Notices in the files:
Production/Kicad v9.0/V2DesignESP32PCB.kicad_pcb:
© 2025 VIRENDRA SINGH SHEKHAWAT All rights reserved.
